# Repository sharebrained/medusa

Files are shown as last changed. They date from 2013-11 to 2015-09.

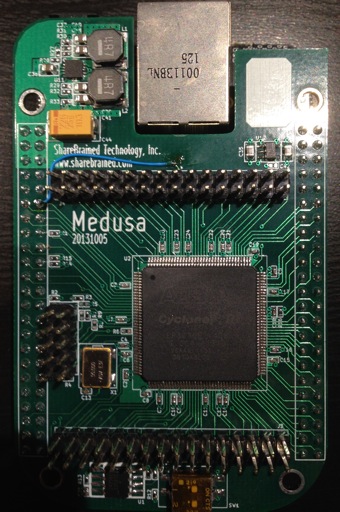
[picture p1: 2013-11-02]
doc/hardware/images/medusa_cape_prototype_0.jpg

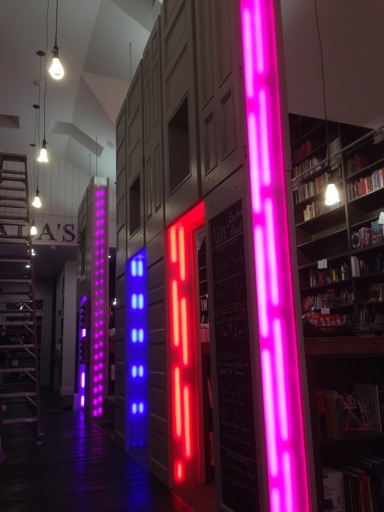
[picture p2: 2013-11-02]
doc/installations/adas_books_seattle/images/adas_20131031.jpg

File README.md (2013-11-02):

Medusa
======

Gonzo LED strip lighting controller, driven from video output that's easy to program.

Medusa prototype installation at Ada's Technical Books, Seattle, WA, USA

The hardware is in three parts:

* Medusa Cape: BeagleBone Black cape that snoops the LCD video output of the BeagleBone and picks off RGB pixel values. Those values are mapped to LED pixels on one of 32 WS2811/WS2812 LED strips of up to 512 LEDs each.
* Medusa TX32: A 32-channel RS-422 transmitter board that sends 4 pairs of RS-422 signalling out of each of eight RJ-45 connectors. Common CAT5/6 Ethernet cabling (TIA-568B) can be used to connect up to four strips on each cable.
* Medusa RX2: A 2-channel RS-422 receiver board that picks off two channels of RS-422 on a cable, and passes the two remaining signals out another cable (so two 2-channel receivers can be chained to use all four channels on a single Ethernet cable).

Medusa Cape prototype

Dependencies
============

For developing this project, the following tools were used:

* Schematic capture and PCB layout: KiCAD -testing branch, builds from late September or early October 2013
* FPGA development and bitstream generation: Altera Quartus II 13.0 SP 1 FPGA development environment, for Windows or Linux
* BeagleBone Linux distribution: Angstrom, September 4, 2013
* Python 2.7

License
=======

The associated software is provided under a GPLv2 license:

Copyright (C) 2013 Jared Boone, ShareBrained Technology, Inc.

This program is free software; you can redistribute it and/or
modify it under the terms of the GNU General Public License
as published by the Free Software Foundation; either version 2
of the License, or (at your option) any later version.

This program is distributed in the hope that it will be useful,
but WITHOUT ANY WARRANTY; without even the implied warranty of
MERCHANTABILITY or FITNESS FOR A PARTICULAR PURPOSE.  See the
GNU General Public License for more details.

You should have received a copy of the GNU General Public License
along with this program; if not, write to the Free Software
Foundation, Inc., 51 Franklin Street, Fifth Floor, Boston, MA
02110-1301, USA.

Contact
=======

Jared Boone <jared@sharebrained.com>

ShareBrained Technology, Inc.

<http://www.sharebrained.com/>

The latest version of this repository can be found at
https://github.com/sharebrained/medusa

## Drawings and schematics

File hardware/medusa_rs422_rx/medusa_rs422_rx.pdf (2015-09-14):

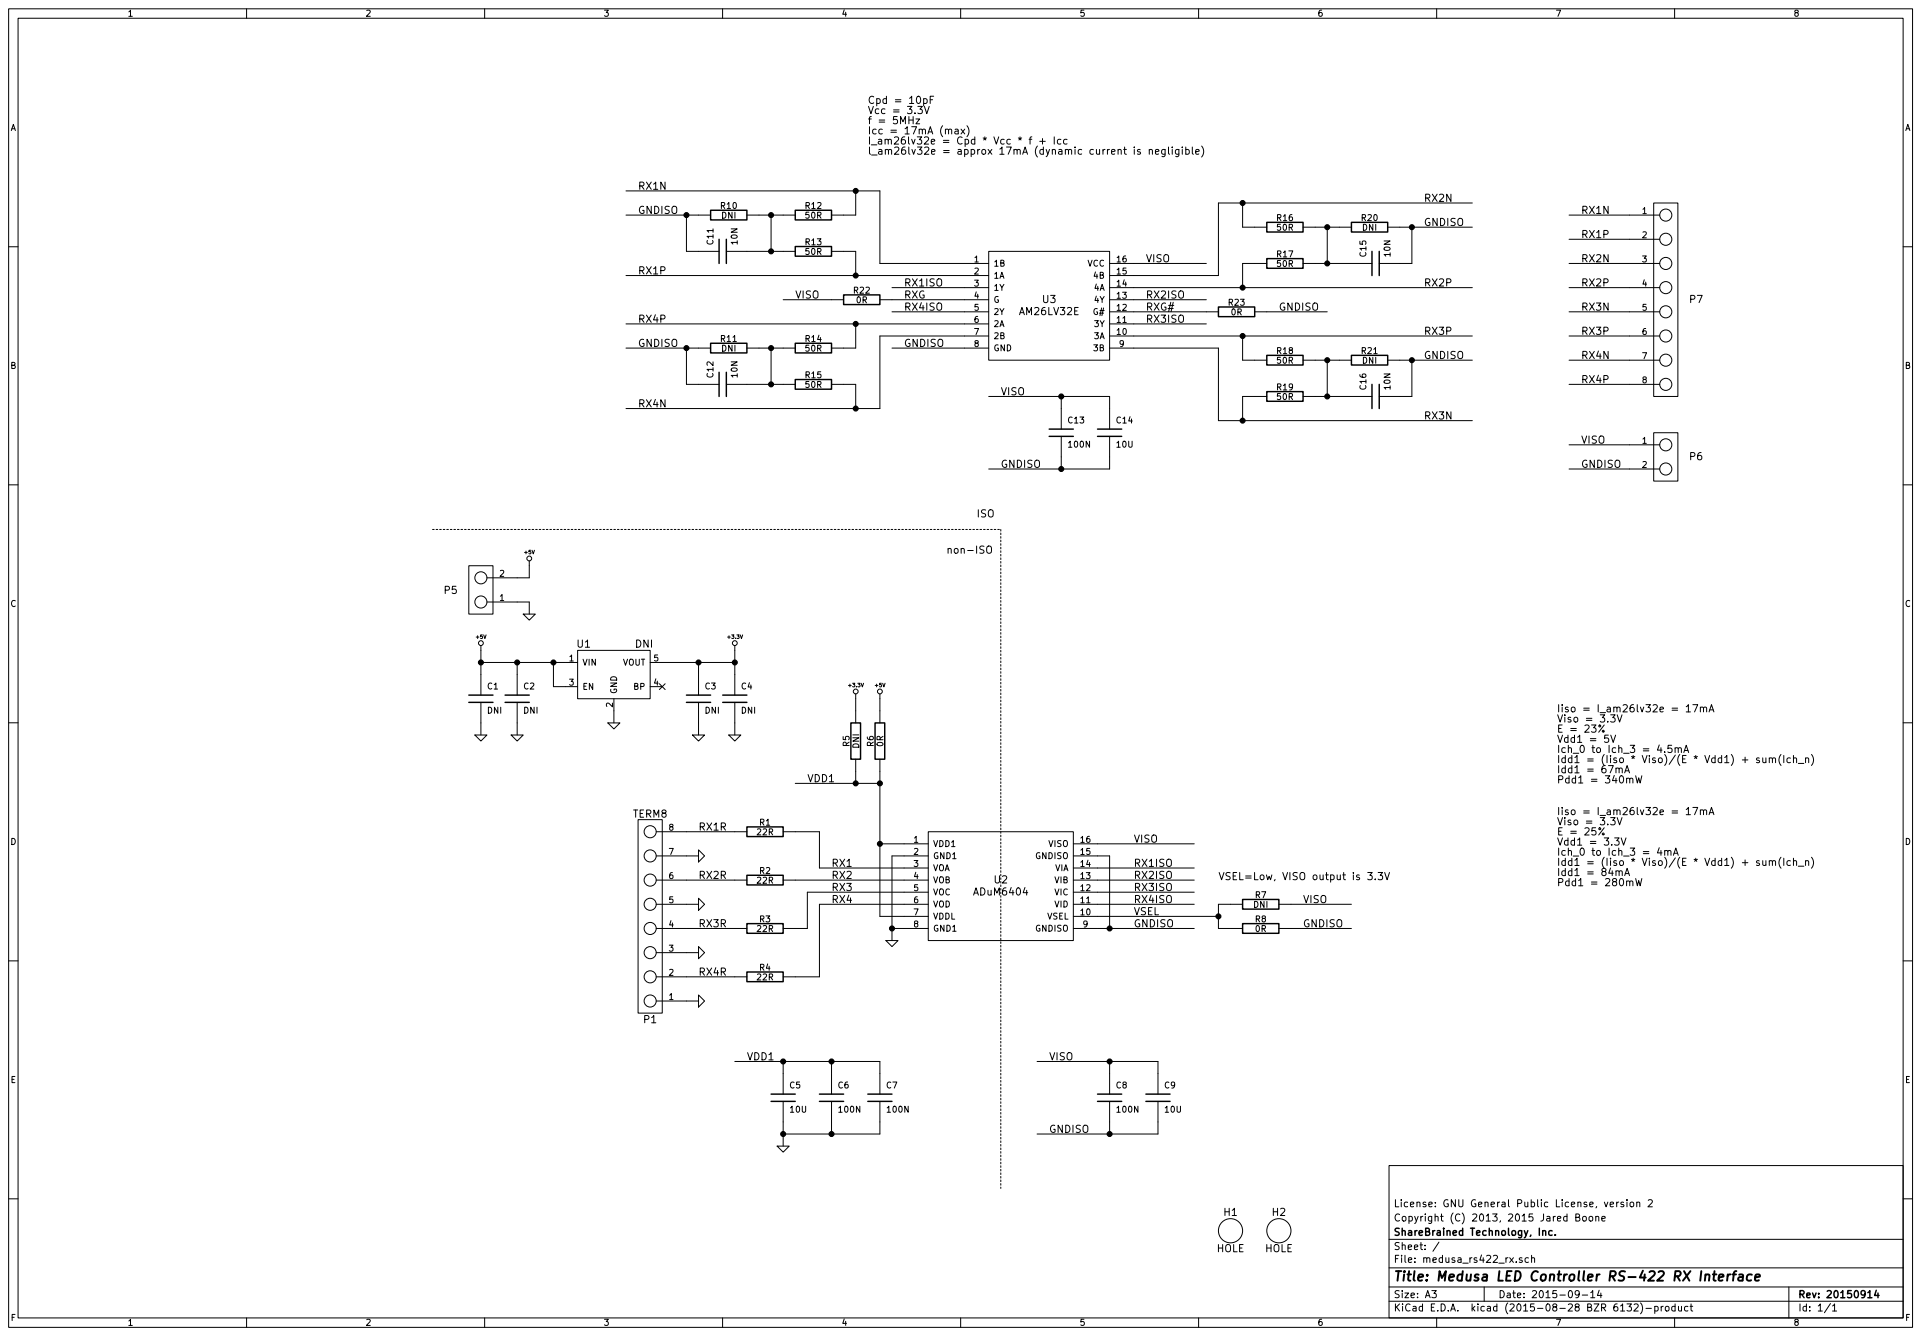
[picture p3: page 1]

Cpd = 10pF Vcc = 3.3V
f = 5MHz
Icc = 17mA (max)
I_am26lv32e = Cpd * Vcc * f + Icc
l_am26lv32e = approx 17mA (dynamic current is negligible)

2 EN 3 BP 4 VOUT 5 U1 DNI +3.3V R5 DNI R6 0R VDD1

License: GNU General Public License, version 2
Copyright (C) 2013, 2015 Jared Boone
File: medusa_rs422_rx.sch Sheet: / ShareBrained Technology, Inc.

Id: 1/1 Title: Medusa LED Controller RS-422 RX Interface

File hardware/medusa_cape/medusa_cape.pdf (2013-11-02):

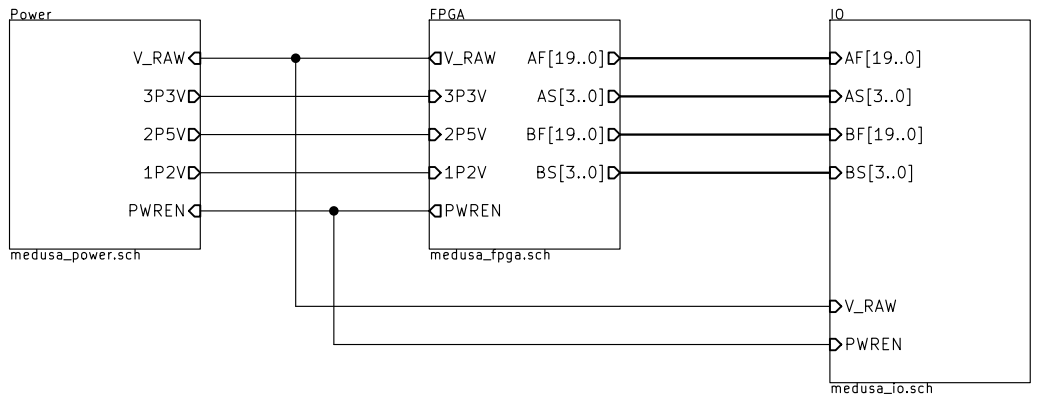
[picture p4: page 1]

License: GNU General Public License, version 2
Copyright (C) 2013 Jared Boone
File: medusa_cape.sch Sheet: / ShareBrained Technology, Inc.

Id: 1/4 Title: Medusa LED Controller for BeagleBone

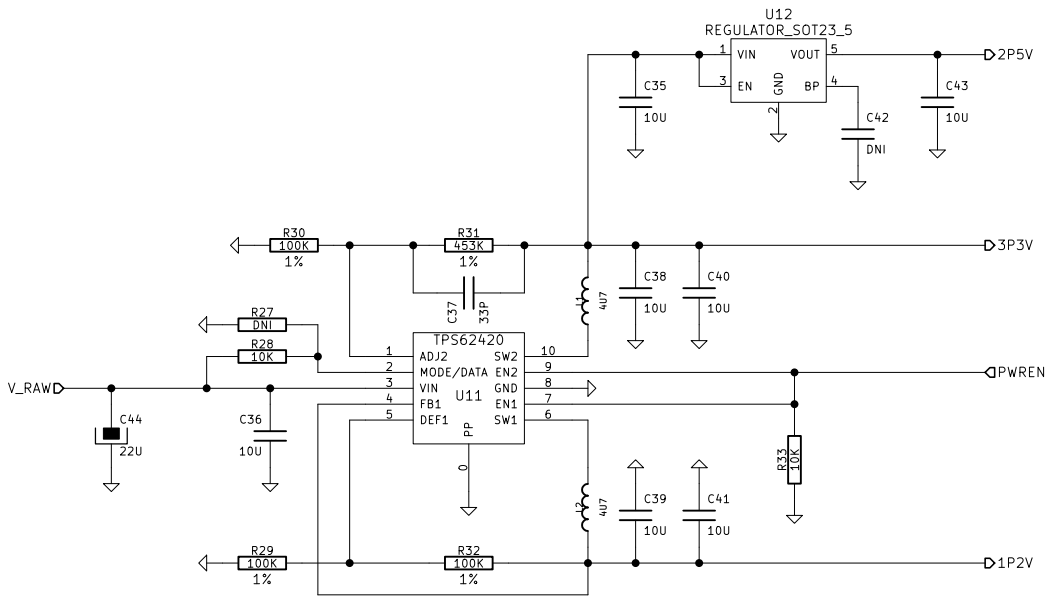
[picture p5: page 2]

0 ADJ2 1 MODE/DATA 2 VIN 3 FB1 4 DEF1 5 SW1 6 EN1 7 GND 8 EN2 9 SW2 10 U11 TPS62420 C41

License: GNU General Public License, version 2
Copyright (C) 2013 Jared Boone
File: medusa_power.sch Sheet: /Power/ ShareBrained Technology, Inc.

Id: 2/4 Title: Medusa LED Controller for BeagleBone

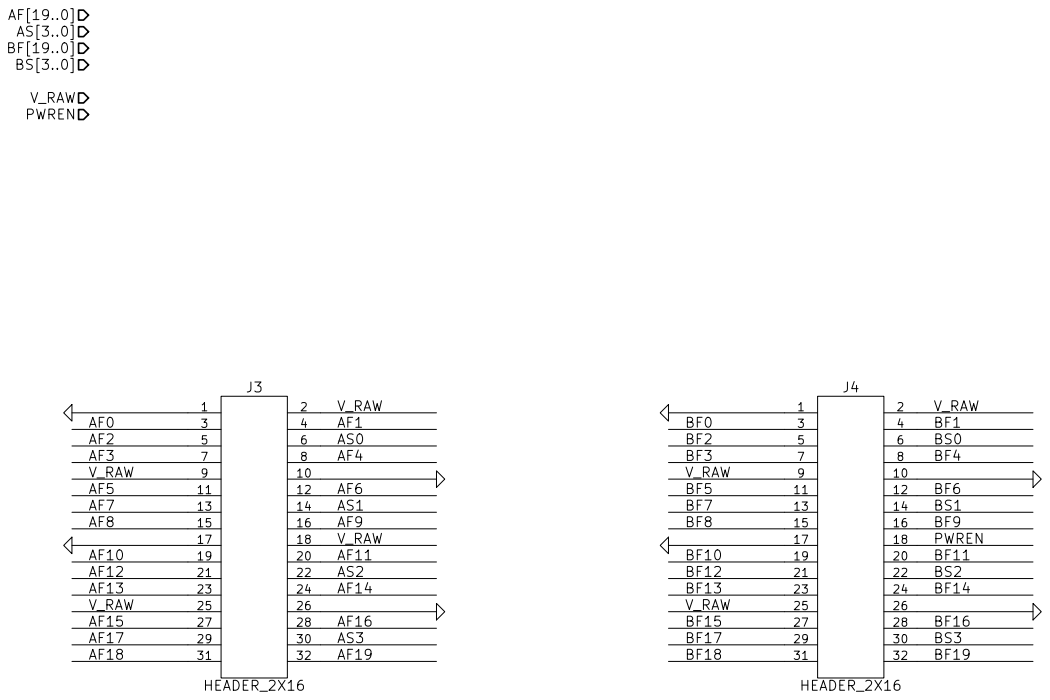
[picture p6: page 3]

License: GNU General Public License, version 2
Copyright (C) 2013 Jared Boone
File: medusa_io.sch Sheet: /IO/ ShareBrained Technology, Inc.

Id: 3/4 Title: Medusa LED Controller for BeagleBone

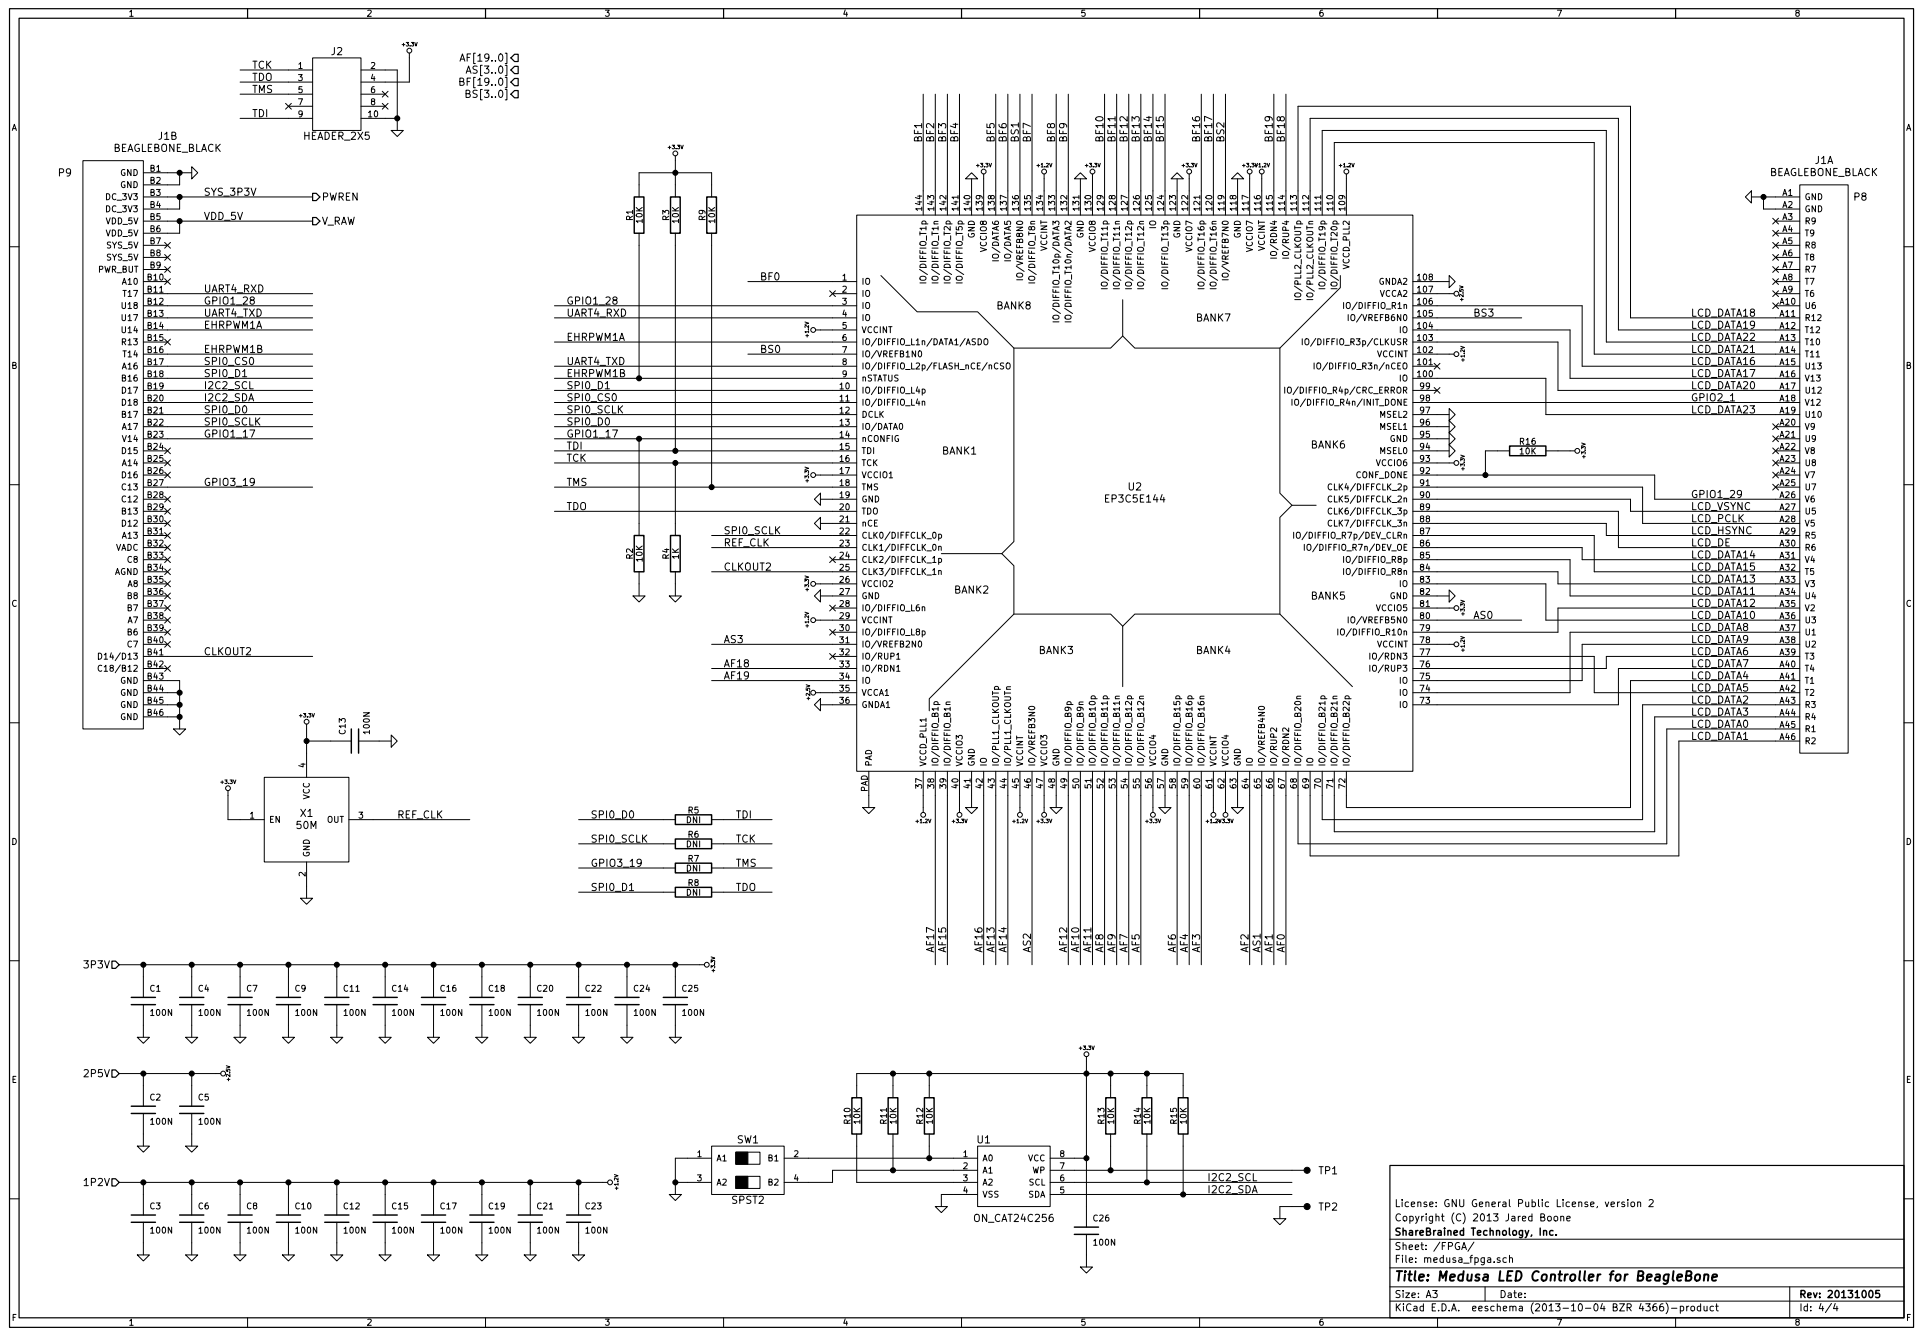
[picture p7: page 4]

LCD_DATA22
LCD_DATA21

License: GNU General Public License, version 2
Copyright (C) 2013 Jared Boone
File: medusa_fpga.sch Sheet: /FPGA/ ShareBrained Technology, Inc.

Id: 4/4 Title: Medusa LED Controller for BeagleBone

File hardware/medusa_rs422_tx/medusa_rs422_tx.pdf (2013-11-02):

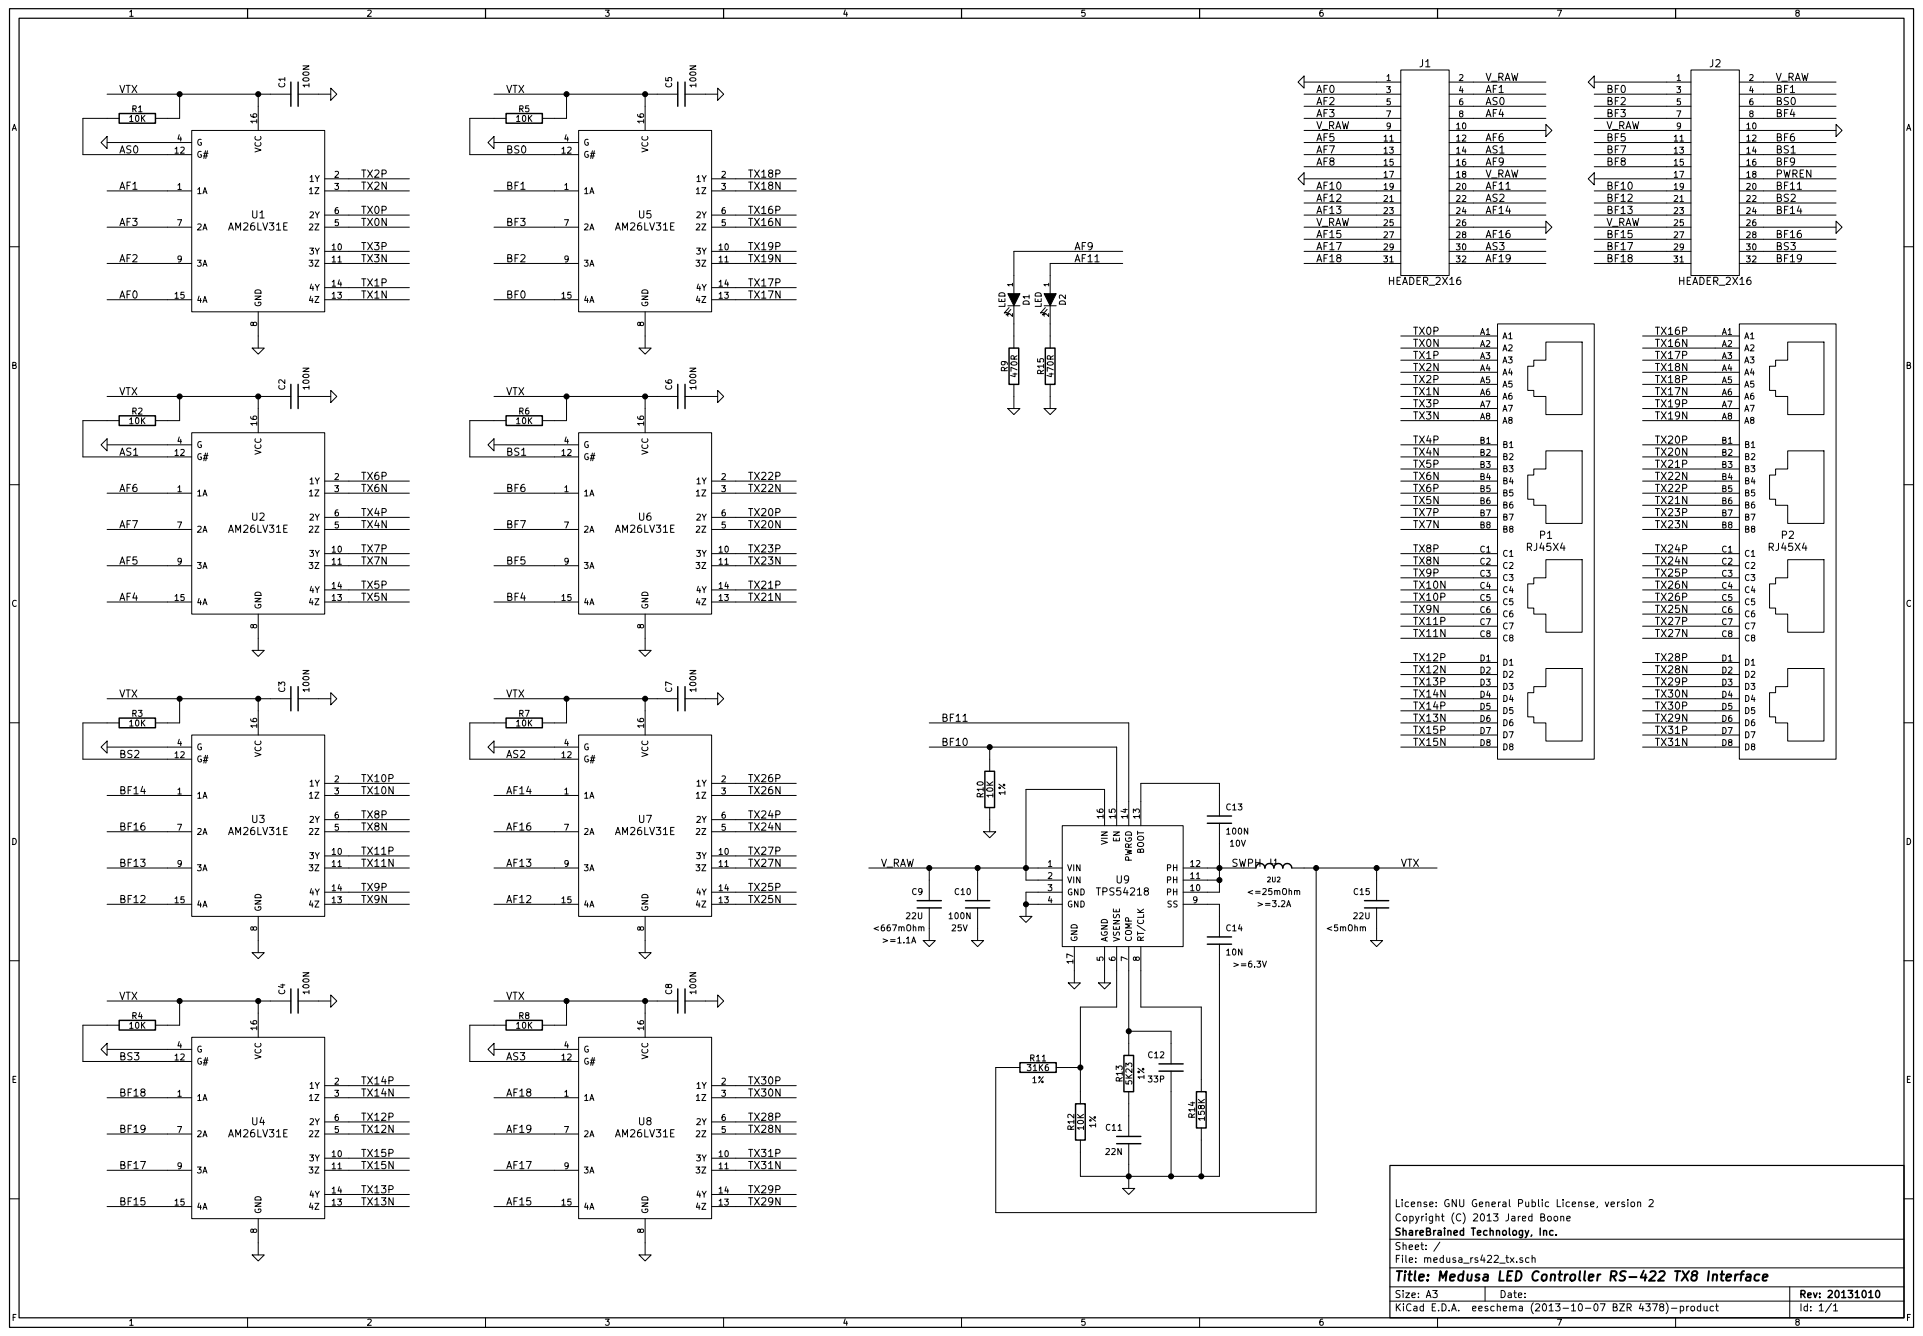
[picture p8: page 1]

License: GNU General Public License, version 2
Copyright (C) 2013 Jared Boone
File: medusa_rs422_tx.sch Sheet: / ShareBrained Technology, Inc.

Id: 1/1 Title: Medusa LED Controller RS-422 TX8 Interface

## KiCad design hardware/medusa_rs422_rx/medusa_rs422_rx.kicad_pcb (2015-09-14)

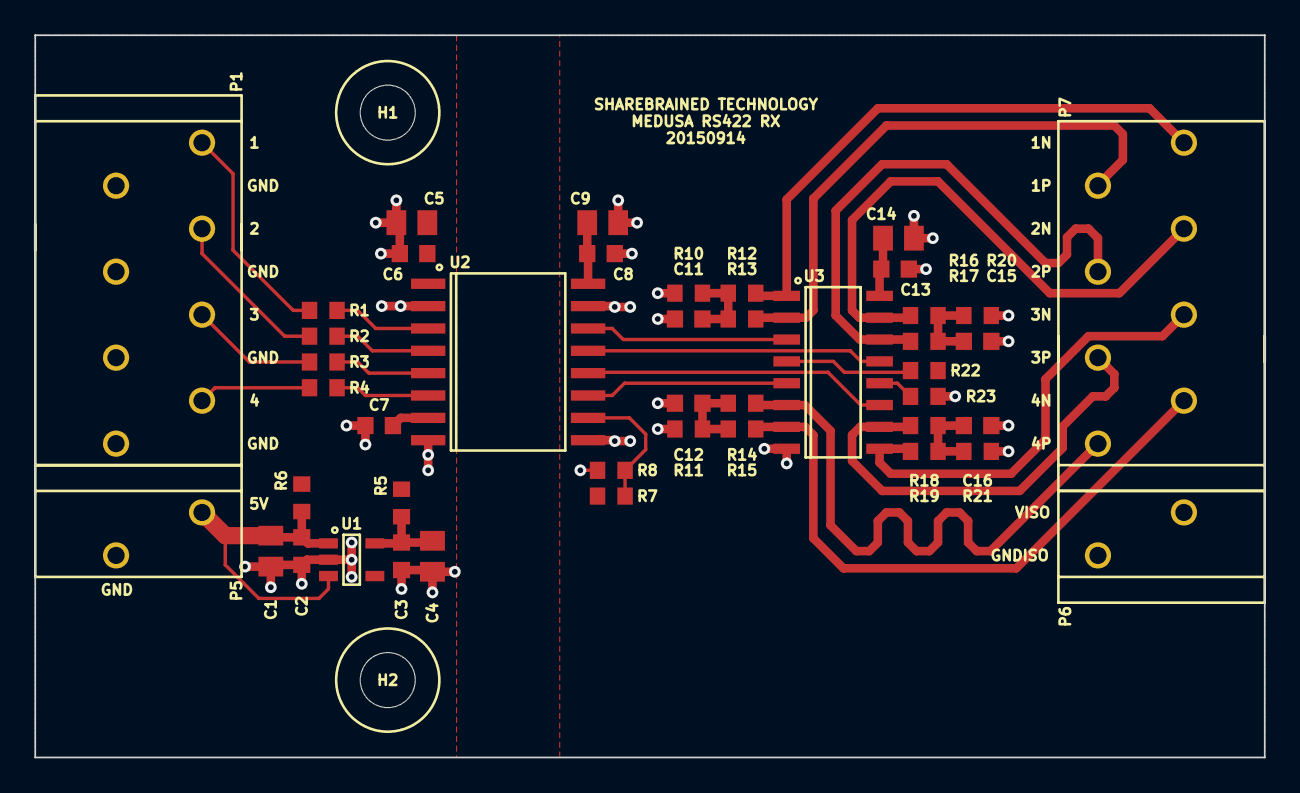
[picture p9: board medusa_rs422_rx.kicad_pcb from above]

Board: 2 copper layers, 71.5 x 42.0 mm, 46 parts (0 on the bottom side), 33 nets.

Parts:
C1, C4: DNI; IPC_CAPC2012X140N
C2, C3: DNI; IPC_CAPC1608X95N
C5, C9, C14: 10U; IPC_CAPC2012X140N
C6, C7, C8, C13: 100N; IPC_CAPC1608X95N
C11, C12, C15, C16: 10N; IPC_CAPC1608X95N
H1, H2: HOLE; HOLE_3P2MM
P1, P7: TERM8; 1990067
P5, P6: TERM2; 1990009
R1, R2, R3, R4: 22R; IPC_RESC1608X55N
R5, R7, R10, R11, R20, R21: DNI; IPC_RESC1608X55N
R6, R8, R22, R23: 0R; IPC_RESC1608X55N
R12, R13, R14, R15, R16, R17, R18, R19: 50R; IPC_RESC1608X55N
U1: DNI; IPC_SOT95P280X110-5N
U2: ADuM6404; IPC_SOIC127P1030X265-16N
U3: AM26LV32E; IPC_SOIC127P600X175-16N

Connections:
+3.3V: C3.1, C4.1, R5.2, U1.5
+5V: C1.1, C2.1, P5.2, R6.2, U1.1, U1.3
/GNDISO: C8.2, C9.2, C11.1, C12.1, C13.2, C14.2, C15.2, C16.2, P6.2, R8.2, R10.1, R11.1, R20.2, R21.2, R23.2, U2.9, U2.15, U3.8
/RX1: R1.1, U2.3
/RX1ISO: U2.14, U3.3
/RX1N: P7.1, R12.2, U3.1
/RX1P: P7.2, R13.2, U3.2
/RX1R: P1.8, R1.2
/RX2: R2.1, U2.4
/RX2ISO: U2.13, U3.13
/RX2N: P7.3, R16.1, U3.15
/RX2P: P7.4, R17.1, U3.14
/RX2R: P1.6, R2.2
/RX3: R3.1, U2.5
/RX3ISO: U2.12, U3.11
/RX3N: P7.5, R19.1, U3.9
/RX3P: P7.6, R18.1, U3.10
/RX3R: P1.4, R3.2
/RX4: R4.1, U2.6
/RX4ISO: U2.11, U3.5
/RX4N: P7.7, R15.2, U3.7
/RX4P: P7.8, R14.2, U3.6
/RX4R: P1.2, R4.2
/RXG: R22.2, U3.4
/RXG#: R23.1, U3.12
/VDD1: C5.1, C6.1, C7.1, R5.1, R6.1, U2.1, U2.7
/VISO: C8.1, C9.1, C13.1, C14.1, P6.1, R7.2, R22.1, U2.16, U3.16
/VSEL: R7.1, R8.1, U2.10
GND: C1.2, C2.2, C3.2, C4.2, C5.2, C6.2, C7.2, P1.1, P1.3, P1.5, P1.7, P5.1, U1.2, U2.2, U2.8
unnamed: C11.2, R10.2, R12.1, R13.1
unnamed: C12.2, R11.2, R14.1, R15.1
unnamed: C15.1, R16.2, R17.2, R20.1
unnamed: C16.1, R18.2, R19.2, R21.1

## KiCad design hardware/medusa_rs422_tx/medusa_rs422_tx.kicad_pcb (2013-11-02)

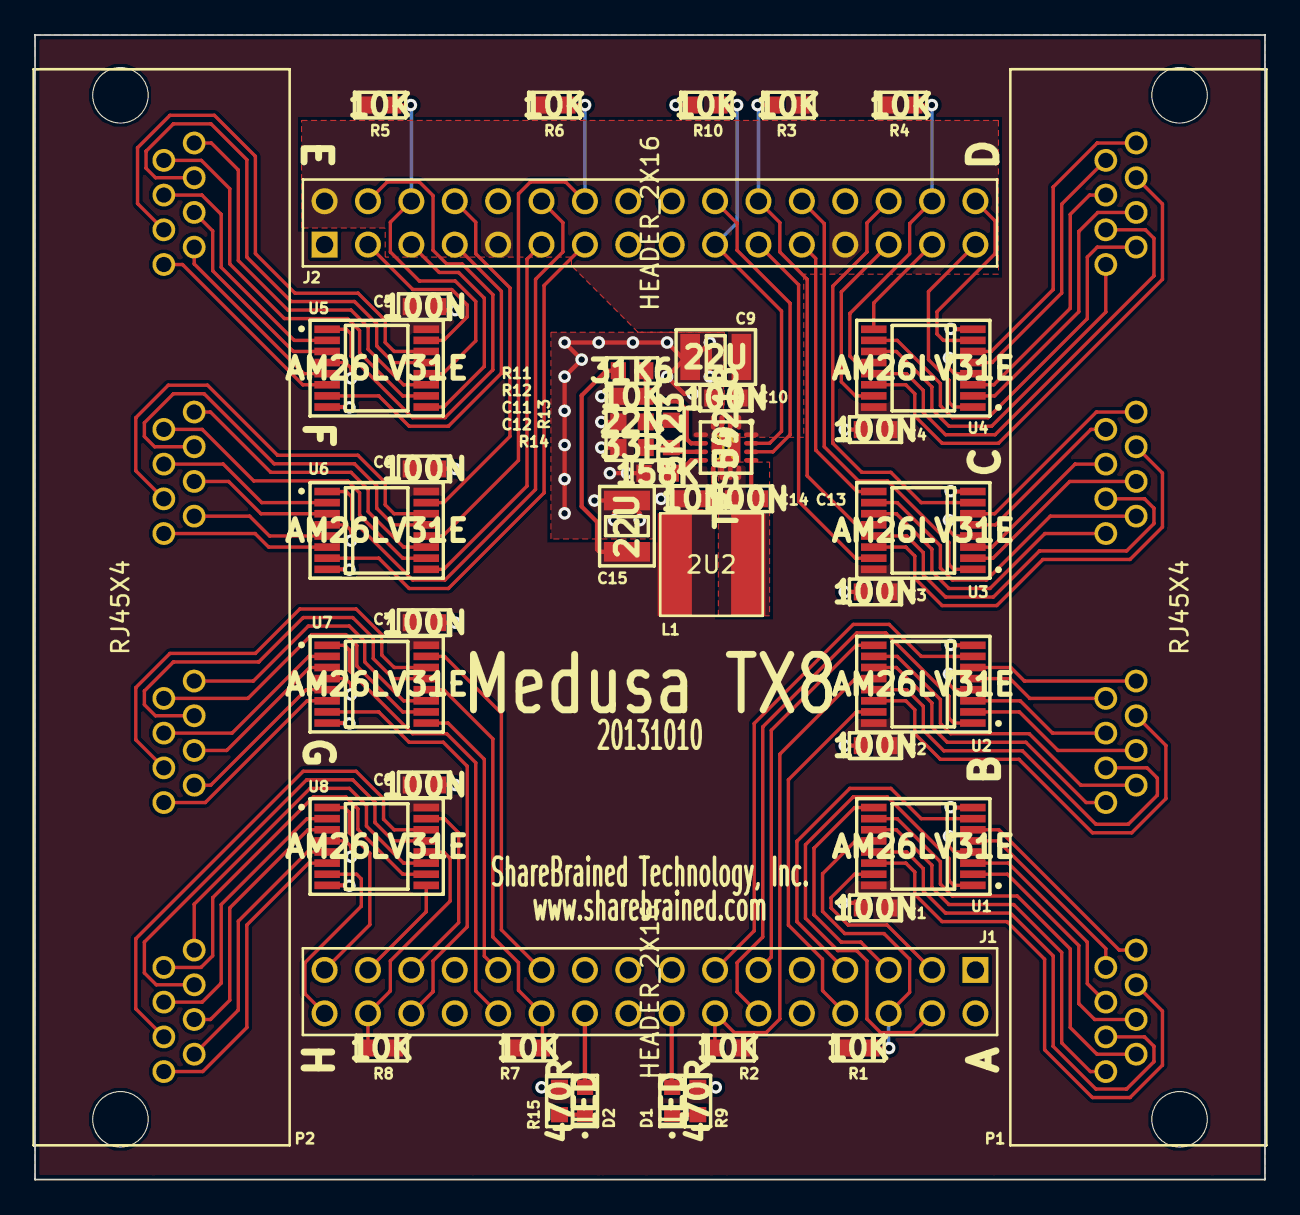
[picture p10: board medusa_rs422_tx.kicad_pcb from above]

Board: 2 copper layers, 72.0 x 67.0 mm, 46 parts (0 on the bottom side), 120 nets.

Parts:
C1, C2, C3, C4, C5, C6, C7, C8, C10, C13: 100N; IPC_CAPC1608X95N
C9, C15: 22U; IPC_CAPC3225X270N
C11: 22N; IPC_CAPC1608X95N
C12: 33P; IPC_CAPC1608X95N
C14: 10N; IPC_CAPC1608X95N
D1, D2: LED; IPC_LEDC1608X60N
J1, J2: HEADER_2X16; HEADER_16X2_TH_254
L1: 2U2; BOURNS_SRN6045
P1, P2: RJ45X4; AMPHENOL_RJHSE508004
R1, R2, R3, R4, R5, R6, R7, R8, R10, R12: 10K; IPC_RESC1608X55N
R9, R15: 470R; IPC_RESC1608X55N
R11: 31K6; IPC_RESC1608X55N
R13: 5K23; IPC_RESC1608X55N
R14: 158K; IPC_RESC1608X55N
U1, U2, U3, U4, U5, U6, U7, U8: AM26LV31E; IPC_SOP65P640X120-16N
U9: TPS54218; TI_RTE_S-PWQFN-N16

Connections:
/AF0: J1.3, U1.15
/AF1: J1.4, U1.1
/AF2: J1.5, U1.9
/AF3: J1.7, U1.7
/AF4: J1.8, U2.15
/AF5: J1.11, U2.9
/AF6: J1.12, U2.1
/AF7: J1.13, U2.7
/AF9: D1.1, J1.16
/AF11: D2.1, J1.20
/AF12: J1.21, U7.15
/AF13: J1.23, U7.9
/AF14: J1.24, U7.1
/AF15: J1.27, U8.15
/AF16: J1.28, U7.7
/AF17: J1.29, U8.9
/AF18: J1.31, U8.1
/AF19: J1.32, U8.7
/AS0: J1.6, R1.1, U1.12
/AS1: J1.14, R2.1, U2.12
/AS2: J1.22, R7.1, U7.12
/AS3: J1.30, R8.1, U8.12
/BF0: J2.3, U5.15
/BF1: J2.4, U5.1
/BF2: J2.5, U5.9
/BF3: J2.7, U5.7
/BF4: J2.8, U6.15
/BF5: J2.11, U6.9
/BF6: J2.12, U6.1
/BF7: J2.13, U6.7
/BF10: J2.19, R10.2, U9.15
/BF11: J2.20, U9.14
/BF12: J2.21, U3.15
/BF13: J2.23, U3.9
/BF14: J2.24, U3.1
/BF15: J2.27, U4.15
/BF16: J2.28, U3.7
/BF17: J2.29, U4.9
/BF18: J2.31, U4.1
/BF19: J2.32, U4.7
/BS0: J2.6, R5.1, U5.12
/BS1: J2.14, R6.1, U6.12
/BS2: J2.22, R3.1, U3.12
/BS3: J2.30, R4.1, U4.12
/SWPH: C13.2, L1.2, U9.10, U9.11, U9.12
/TX0N: P1.A2, U1.5
/TX0P: P1.A1, U1.6
/TX1N: P1.A6, U1.13
/TX1P: P1.A3, U1.14
/TX2N: P1.A4, U1.3
/TX2P: P1.A5, U1.2
/TX3N: P1.A8, U1.11
/TX3P: P1.A7, U1.10
/TX4N: P1.B2, U2.5
/TX4P: P1.B1, U2.6
/TX5N: P1.B6, U2.13
/TX5P: P1.B3, U2.14
/TX6N: P1.B4, U2.3
/TX6P: P1.B5, U2.2
/TX7N: P1.B8, U2.11
/TX7P: P1.B7, U2.10
/TX8N: P1.C2, U3.5
/TX8P: P1.C1, U3.6
/TX9N: P1.C6, U3.13
/TX9P: P1.C3, U3.14
/TX10N: P1.C4, U3.3
/TX10P: P1.C5, U3.2
/TX11N: P1.C8, U3.11
/TX11P: P1.C7, U3.10
/TX12N: P1.D2, U4.5
/TX12P: P1.D1, U4.6
/TX13N: P1.D6, U4.13
/TX13P: P1.D3, U4.14
/TX14N: P1.D4, U4.3
/TX14P: P1.D5, U4.2
/TX15N: P1.D8, U4.11
/TX15P: P1.D7, U4.10
/TX16N: P2.A2, U5.5
/TX16P: P2.A1, U5.6
/TX17N: P2.A6, U5.13
/TX17P: P2.A3, U5.14
/TX18N: P2.A4, U5.3
/TX18P: P2.A5, U5.2
/TX19N: P2.A8, U5.11
/TX19P: P2.A7, U5.10
/TX20N: P2.B2, U6.5
/TX20P: P2.B1, U6.6
/TX21N: P2.B6, U6.13
/TX21P: P2.B3, U6.14
/TX22N: P2.B4, U6.3
/TX22P: P2.B5, U6.2
/TX23N: P2.B8, U6.11
/TX23P: P2.B7, U6.10
/TX24N: P2.C2, U7.5
/TX24P: P2.C1, U7.6
/TX25N: P2.C6, U7.13
/TX25P: P2.C3, U7.14
/TX26N: P2.C4, U7.3
/TX26P: P2.C5, U7.2
/TX27N: P2.C8, U7.11
/TX27P: P2.C7, U7.10
/TX28N: P2.D2, U8.5
/TX28P: P2.D1, U8.6
/TX29N: P2.D6, U8.13
/TX29P: P2.D3, U8.14
/TX30N: P2.D4, U8.3
/TX30P: P2.D5, U8.2
/TX31N: P2.D8, U8.11
/TX31P: P2.D7, U8.10
/VTX: C1.1, C2.1, C3.1, C4.1, C5.1, C6.1, C7.1, C8.1, C15.1, L1.1, R1.2, R2.2, R3.2, R4.2, R5.2, R6.2, R7.2, R8.2, R11.1, U1.16, U2.16, U3.16, U4.16, U5.16, U6.16, U7.16, U8.16
/V_RAW: C9.1, C10.1, J1.2, J1.9, J1.18, J1.25, J2.2, J2.9, J2.25, U9.1, U9.2, U9.16
GND: C1.2, C2.2, C3.2, C4.2, C5.2, C6.2, C7.2, C8.2, C9.2, C10.2, C11.2, C12.2, C14.2, C15.2, J1.1, J1.10, J1.17, J1.26, J2.1, J2.10, J2.17, J2.26, R9.1, R10.1, R12.1, R14.1, R15.1, U1.4, U1.8, U2.4, U2.8, U3.4, U3.8, U4.4, U4.8, U5.4, U5.8, U6.4, U6.8, U7.4, U7.8, U8.4, U8.8, U9.3, U9.4, U9.5, U9.17
Net-<C11-Pad1>: C11.1, R13.1
Net-<C12-Pad1>: C12.1, R13.2, U9.7
Net-<C13-Pad1>: C13.1, U9.13
Net-<C14-Pad1>: C14.1, U9.9
Net-<D1-Pad2>: D1.2, R9.2
Net-<D2-Pad2>: D2.2, R15.2
Net-<R11-Pad2>: R11.2, R12.2, U9.6
Net-<R14-Pad2>: R14.2, U9.8

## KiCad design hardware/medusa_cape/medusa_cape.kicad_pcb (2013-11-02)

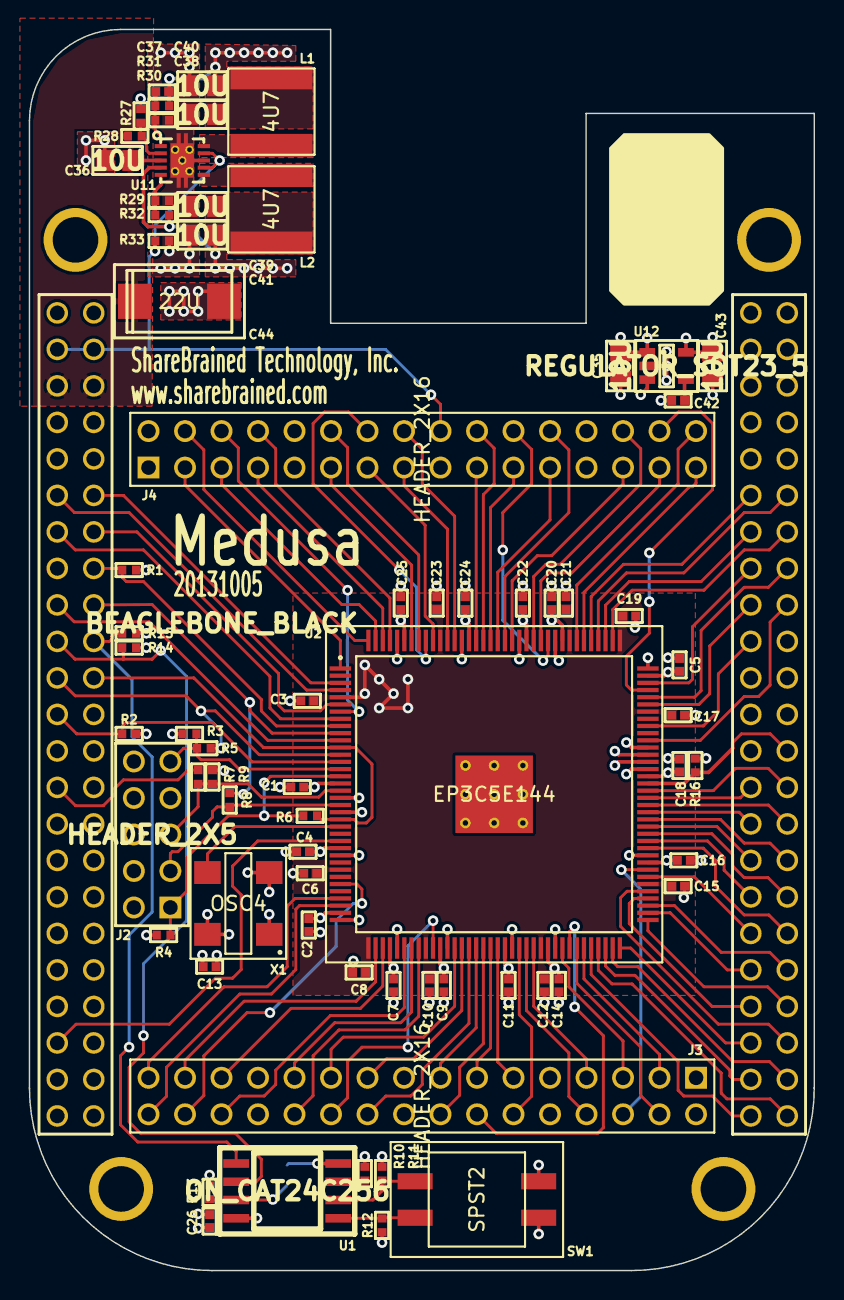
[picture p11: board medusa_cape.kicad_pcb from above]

Board: 4 copper layers, 54.6 x 86.4 mm, 73 parts (0 on the bottom side), 113 nets.

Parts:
C1, C2, C3, C4, C5, C6, C7, C8, C9, C10, C11, C12, C13, C14, C15, C16, C17, C18, C19, C20, C21, C22, C23, C24, C25, C26: 100N; IPC_CAPC1005X55N
C35, C36, C38, C39, C40, C41, C43: 10U; IPC_CAPC2012X140N
C37: 33P; IPC_CAPC1005X55N
C42: DNI; IPC_CAPC1005X55N
C44: 22U; IPC_CAPMP7343X310N
J1: BEAGLEBONE_BLACK; beaglebone_black
J2: HEADER_2X5; HEADER_5X2_TH_254
J3, J4: HEADER_2X16; HEADER_16X2_TH_254
L1, L2: 4U7; NR6028
R1, R2, R3, R9, R10, R11, R12, R13, R14, R15, R16, R28, R33: 10K; IPC_RESC1005X40N
R4: 1K; IPC_RESC1005X40N
R5, R6, R7, R8, R27: DNI; IPC_RESC1005X40N
R29, R30, R31, R32: R; IPC_RESC1005X40N
SW1: SPST2; 219-2MST
TP1, TP2: TP; TP_1MM
U1: ON_CAT24C256; IPC_SOIC127P780X205-8N
U2: EP3C5E144; QFP50P2200X2200X160-145N_ALTERA
U11: TPS62420; TI_DRC_S-PVSON-N10
U12: REGULATOR_SOT23_5; IPC_SOT95P280X110-5N
X1: OSC4; OSCSC508P500X700X180-4N

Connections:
+1.2V: C3.1, C6.1, C8.1, C10.1, C12.1, C15.1, C17.1, C19.1, C21.1, C23.1, C39.2, C41.2, L2.2, R32.2, U2.5, U2.29, U2.37, U2.45, U2.61, U2.78, U2.102, U2.109, U2.116, U2.134, U11.4
+2.5V: C2.1, C5.1, C43.1, U2.35, U2.107, U12.5
+3.3V: C1.1, C4.1, C7.1, C9.1, C11.1, C13.1, C14.1, C16.1, C18.1, C20.1, C22.1, C24.1, C25.1, C26.1, C35.1, C37.2, C38.1, C40.1, J2.4, L1.1, R1.1, R3.1, R9.1, R10.1, R11.1, R12.1, R13.1, R14.1, R15.1, R16.1, R31.2, U1.8, U2.17, U2.26, U2.40, U2.47, U2.56, U2.62, U2.81, U2.93, U2.117, U2.122, U2.130, U2.139, U12.1, U12.3, X1.1, X1.4
/FPGA/AF0: J3.3, U2.67
/FPGA/AF1: J3.4, U2.66
/FPGA/AF2: J3.5, U2.64
/FPGA/AF3: J3.7, U2.60
/FPGA/AF4: J3.8, U2.59
/FPGA/AF5: J3.11, U2.55
/FPGA/AF6: J3.12, U2.58
/FPGA/AF7: J3.13, U2.54
/FPGA/AF8: J3.15, U2.52
/FPGA/AF9: J3.16, U2.53
/FPGA/AF10: J3.19, U2.50
/FPGA/AF11: J3.20, U2.51
/FPGA/AF12: J3.21, U2.49
/FPGA/AF13: J3.23, U2.43
/FPGA/AF14: J3.24, U2.44
/FPGA/AF15: J3.27, U2.39
/FPGA/AF16: J3.28, U2.42
/FPGA/AF17: J3.29, U2.38
/FPGA/AF18: J3.31, U2.33
/FPGA/AF19: J3.32, U2.34
/FPGA/AS0: J3.6, U2.80
/FPGA/AS1: J3.14, U2.65
/FPGA/AS2: J3.22, U2.46
/FPGA/AS3: J3.30, U2.31
/FPGA/BF0: J4.3, U2.1
/FPGA/BF1: J4.4, U2.144
/FPGA/BF2: J4.5, U2.143
/FPGA/BF3: J4.7, U2.142
/FPGA/BF4: J4.8, U2.141
/FPGA/BF5: J4.11, U2.138
/FPGA/BF6: J4.12, U2.137
/FPGA/BF7: J4.13, U2.135
/FPGA/BF8: J4.15, U2.133
/FPGA/BF9: J4.16, U2.132
/FPGA/BF10: J4.19, U2.129
/FPGA/BF11: J4.20, U2.128
/FPGA/BF12: J4.21, U2.127
/FPGA/BF13: J4.23, U2.126
/FPGA/BF14: J4.24, U2.125
/FPGA/BF15: J4.27, U2.124
/FPGA/BF16: J4.28, U2.121
/FPGA/BF17: J4.29, U2.120
/FPGA/BF18: J4.31, U2.114
/FPGA/BF19: J4.32, U2.115
/FPGA/BS0: J4.6, U2.7
/FPGA/BS1: J4.14, U2.136
/FPGA/BS2: J4.22, U2.119
/FPGA/BS3: J4.30, U2.105
/FPGA/CLKOUT2: J1.B41, U2.25
/FPGA/EHRPWM1A: J1.B14, U2.6
/FPGA/EHRPWM1B: J1.B16, R1.2, U2.9
/FPGA/GPIO1_17: J1.B23, R2.1, U2.14
/FPGA/GPIO1_28: J1.B12, U2.3
/FPGA/GPIO1_29: J1.A26, R16.2, U2.92
/FPGA/GPIO2_1: J1.A18, U2.98
/FPGA/GPIO3_19: J1.B27, R7.2
/FPGA/I2C2_SCL: J1.B19, R14.2, U1.6
/FPGA/I2C2_SDA: J1.B20, R15.2, U1.5
/FPGA/LCD_DATA0: J1.A45, U2.68
/FPGA/LCD_DATA1: J1.A46, U2.69
/FPGA/LCD_DATA2: J1.A43, U2.70
/FPGA/LCD_DATA3: J1.A44, U2.71
/FPGA/LCD_DATA4: J1.A41, U2.72
/FPGA/LCD_DATA5: J1.A42, U2.77
/FPGA/LCD_DATA6: J1.A39, U2.76
/FPGA/LCD_DATA7: J1.A40, U2.73
/FPGA/LCD_DATA8: J1.A37, U2.74
/FPGA/LCD_DATA9: J1.A38, U2.75
/FPGA/LCD_DATA10: J1.A36, U2.83
/FPGA/LCD_DATA11: J1.A34, U2.85
/FPGA/LCD_DATA12: J1.A35, U2.79
/FPGA/LCD_DATA13: J1.A33, U2.84
/FPGA/LCD_DATA14: J1.A31, U2.86
/FPGA/LCD_DATA15: J1.A32, U2.87
/FPGA/LCD_DATA16: J1.A15, U2.106
/FPGA/LCD_DATA17: J1.A16, U2.104
/FPGA/LCD_DATA18: J1.A11, U2.113
/FPGA/LCD_DATA19: J1.A12, U2.112
/FPGA/LCD_DATA20: J1.A17, U2.103
/FPGA/LCD_DATA21: J1.A14, U2.110
/FPGA/LCD_DATA22: J1.A13, U2.111
/FPGA/LCD_DATA23: J1.A19, U2.100
/FPGA/LCD_DE: J1.A30, U2.89
/FPGA/LCD_HSYNC: J1.A29, U2.88
/FPGA/LCD_PCLK: J1.A28, U2.91
/FPGA/LCD_VSYNC: J1.A27, U2.90
/FPGA/PWREN: J1.B3, J1.B4, J4.18, R33.2, U11.7, U11.9
/FPGA/REF_CLK: U2.23, X1.3
/FPGA/SPI0_CS0: J1.B17, U2.11
/FPGA/SPI0_D0: J1.B21, R5.2, U2.13
/FPGA/SPI0_D1: J1.B18, R8.2, U2.10
/FPGA/SPI0_SCLK: J1.B22, R6.2, U2.12, U2.22
/FPGA/TCK: J2.1, R4.1, R6.1, U2.16
/FPGA/TDI: J2.9, R3.2, R5.1, U2.15
/FPGA/TDO: J2.3, R8.1, U2.20
/FPGA/TMS: J2.5, R7.1, R9.2, U2.18
/FPGA/UART4_RXD: J1.B11, U2.4
/FPGA/UART4_TXD: J1.B13, U2.8
/FPGA/V_RAW: C36.1, C44.1, J1.B5, J1.B6, J3.2, J3.9, J3.18, J3.25, J4.2, J4.9, J4.25, R28.1, U11.3
GND: C1.2, C2.2, C3.2, C4.2, C5.2, C6.2, C7.2, C8.2, C9.2, C10.2, C11.2, C12.2, C13.2, C14.2, C15.2, C16.2, C17.2, C18.2, C19.2, C20.2, C21.2, C22.2, C23.2, C24.2, C25.2, C26.2, C35.2, C36.2, C38.2, C39.1, C40.2, C41.1, C42.2, C43.2, C44.2, J1.A1, J1.A2, J1.B1, J1.B2, J1.B43, J1.B44, J1.B45, J1.B46, J2.2, J2.10, J3.1, J3.10, J3.17, J3.26, J4.1, J4.10, J4.17, J4.26, R2.2, R4.2, R27.1, R29.1, R30.1, R33.1, SW1.1, SW1.3, TP2.1, U1.4, U2.19, U2.21, U2.27, U2.36, U2.41, U2.48, U2.57, U2.63, U2.82, U2.94, U2.95, U2.96, U2.97, U2.108, U2.118, U2.123, U2.131, U2.140, U2.PAD, U11.0, U11.8, U12.2, X1.2
Net-<C37-Pad1>: C37.1, R30.2, R31.1, U11.1
Net-<C42-Pad1>: C42.1, U12.4
Net-<L1-Pad2>: L1.2, U11.10
Net-<L2-Pad1>: L2.1, U11.6
Net-<R10-Pad2>: R10.2, U1.3
Net-<R11-Pad2>: R11.2, SW1.4, U1.2
Net-<R12-Pad2>: R12.2, SW1.2, U1.1
Net-<R13-Pad2>: R13.2, TP1.1, U1.7
Net-<R27-Pad2>: R27.2, R28.2, U11.2
Net-<R29-Pad2>: R29.2, R32.1, U11.5

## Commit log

2013-11-02 Initial release of Medusa hardware (BeagleBone cape, TX32, RX2) and HDL code.
    [medusa_cape.kicad_pcb, medusa_cape.sch, medusa_fpga.sch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]
2013-12-05 Extract signal led_pixel_count_advance.
2013-12-05 Extract led_pixel_count_init value and use it at reset to address first-pass strip readout bug, where 512 pixels are transmitted before settling into the proper LED strip length cadence.
2013-12-05 Renamed led_pixel_last to be more descriptive "led_pixel_count_last".
2013-12-05 Refactor signals of led_symbol_count*, and rename an ambiguous signal.
2015-09-14 Complete rebake of RX board.
    Added ground isolation.
    Changed receiver IC to better match transmitter specs.
    Added somewhat sketchy termination + ground reference mechanism.
    Removed RJ45 connectors and passthrough in favor of a single board with four channels and terminal blocks.
    Added separate terminal blocks for power supply (+5V) and isolated power connections. If we run dedicated ground reference wires from the transmitters, this is where they'll connect.
    Added optional power regulator for 3.3V operation, if we want to experiment with MCUs at the receivers.
    [medusa_rs422_rx.kicad_pcb, medusa_rs422_rx.sch]
2015-10-11 Un-cross strip output 16 and 17.
    Wall wiring was redone, and this eccentricity was eliminated in the process.
